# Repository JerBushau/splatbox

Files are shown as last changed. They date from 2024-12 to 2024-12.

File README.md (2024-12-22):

# Splatbox Fightstick

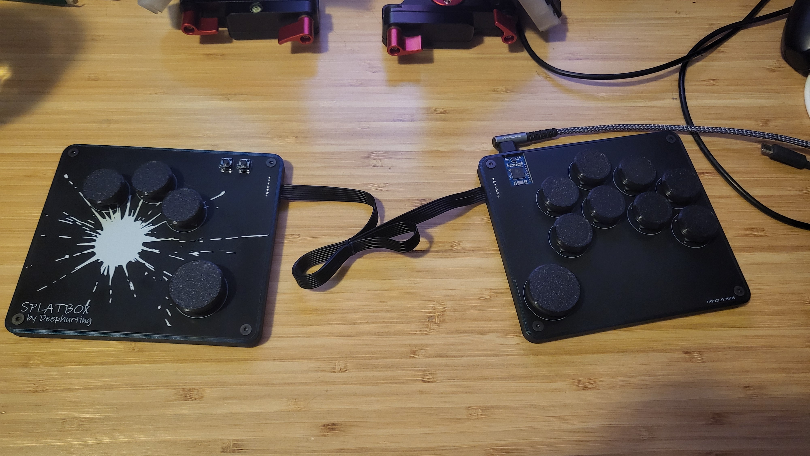
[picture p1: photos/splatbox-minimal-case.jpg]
Splatbox


A prototype for a split ergonomic fightstick inspired by [Flatbox](https://github.com/jfedor2/flatbox). Designed to provide a more ergonomic and comfortable DIY option for anyone that might be interested in such a thing. This project also serves as an opportunity for me to do some handwiring and learn Autodesk Fusion and KiCad.

## BOM

- PCB
- Waveshare rp2040 zero
- 13 x choc switches (pictured are [LowProKBs Twilight switches](https://lowprokb.ca/collections/switches/products/ambients-silent-choc-switches?variant=44873426436260))
- 2 x tact switches (Start and Select buttons)
- 8 x M3 6mm screws
- 8 x M3 heat-set inserts
- 28 awg ribbon cable (at least 7 pin)
- 3D printed case (minimal)
- 11 x Small 3D printed [button caps](https://github.com/jfedor2/flatbox/tree/master/3d-printed-buttoncaps)
- 2 x Big 3D printed [button caps](https://github.com/jfedor2/flatbox/tree/master/3d-printed-buttoncaps)
- Rubber feet

## Building

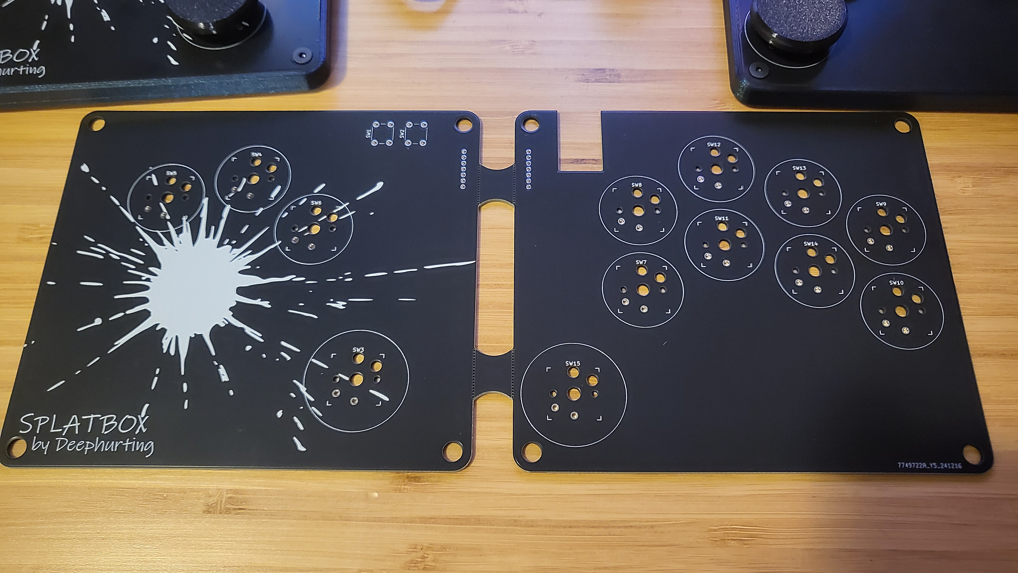
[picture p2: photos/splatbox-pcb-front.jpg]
Splatbox Splatbox pcb


While still far from a finished product, the pcb certainly adds to the stability and reliability of the build. The tolerances for the case files are extremely tight, so you will likely need to scale it up some small fraction, I had to sand the pcb a bit to get a good fit.

- Set heat-set inserts in case
- Solder rp2040 zero
- Solder switches
- Solder ribbon cable to one side or the other
- Feed cable through the holes and solder the remaining side
- Screw the pcb to the case

## TODO:

- [x] PCB design: Create a custom PCB to improve durability and simplify the design
- [x] Case re-design to accommodate the PCB layout
  - [ ] More case options
- [ ] More modularity: Implement a way to extend or shorten the cable
- [ ] Wireless version (dongle approach): Explore a wireless setup using XIAO Seeeds

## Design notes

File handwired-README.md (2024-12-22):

# Splatbox Fightstick

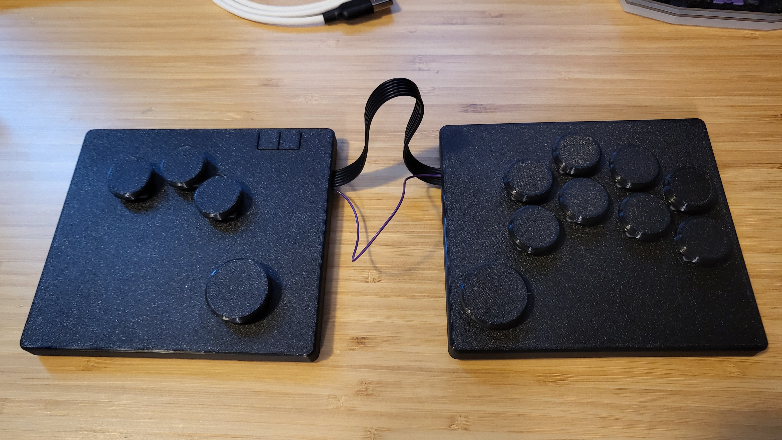
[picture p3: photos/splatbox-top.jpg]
Splatbox

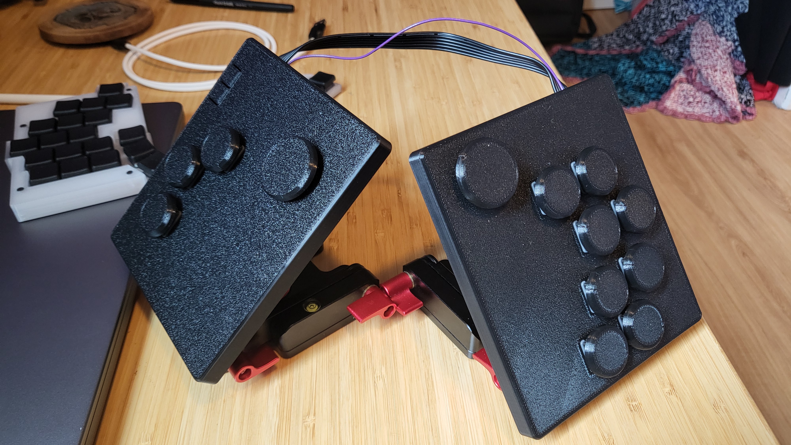
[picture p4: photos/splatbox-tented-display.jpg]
Splatbox Splatbox with tenting


An early prototype for a split ergonomic fightstick inspired by [Flatbox](https://github.com/jfedor2/flatbox). Designed to provide a more ergonomic and comfortable DIY option for anyone that might be interested in such a thing. This project also serves as an opportunity for me to learn Autodesk Fusion and KiCad.

## BOM (as shown)

- Waveshare rp2040 zero
- 13 x choc switches (pictured are [LowProKBs Twilight switches](https://lowprokb.ca/collections/switches/products/ambients-silent-choc-switches?variant=44873426436260))
- 2 x tact switches (Start and Select buttons)
- 8 x M3 6mm screws
- 8 x M3 heat-set inserts
- Wire
- 3D printed case
- 11 x Small 3D printed [button caps](https://github.com/jfedor2/flatbox/tree/master/3d-printed-buttoncaps)
- 2 x Big 3D printed [button caps](https://github.com/jfedor2/flatbox/tree/master/3d-printed-buttoncaps)
- Rubber feet

## Building

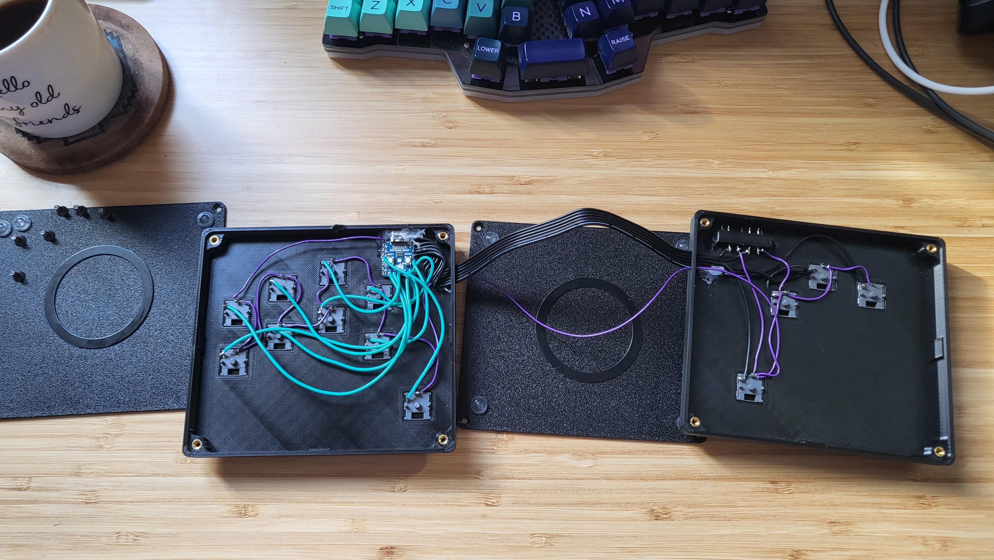
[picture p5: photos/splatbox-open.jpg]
Splatbox Splatbox open


This is very much a Proof of Concept, and the build was quick and dirty. But, if you want to make one here's a rundown of the steps:

- Flash the RP2040 ([GP2040-CE firmware](https://gp2040-ce.info/downloads/))
- 3D print the case (I used PETG, but it has a bit too much flex; consider using a more rigid filament)
- Set the M3 heat-set inserts
- Glue the tact switches to the tact switch holder (3D-printed)
- Glue the tact switch holder to the case
- Insert choc switches into the case
- Wire everything up to the RP2040 ([wiring guide](https://gp2040-ce.info/controller-build/wiring/#waveshare-rp2040-zero))
- Glue as needed
- Assemble the case by screwing on the bottom with 8 x M3 screws

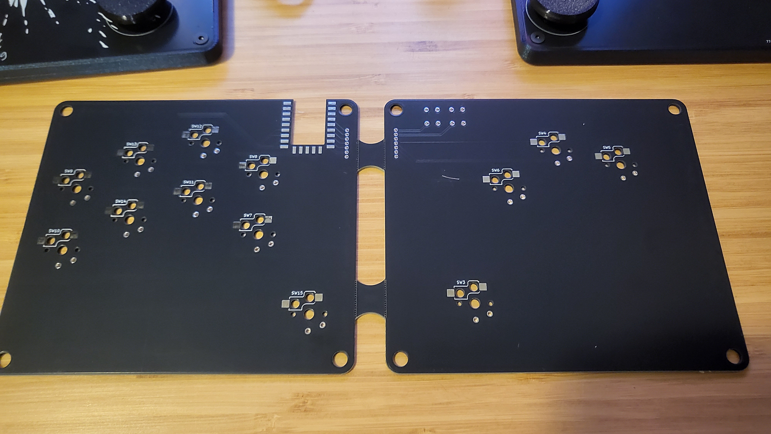
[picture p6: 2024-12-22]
photos/splatbox-pcb-back.jpg

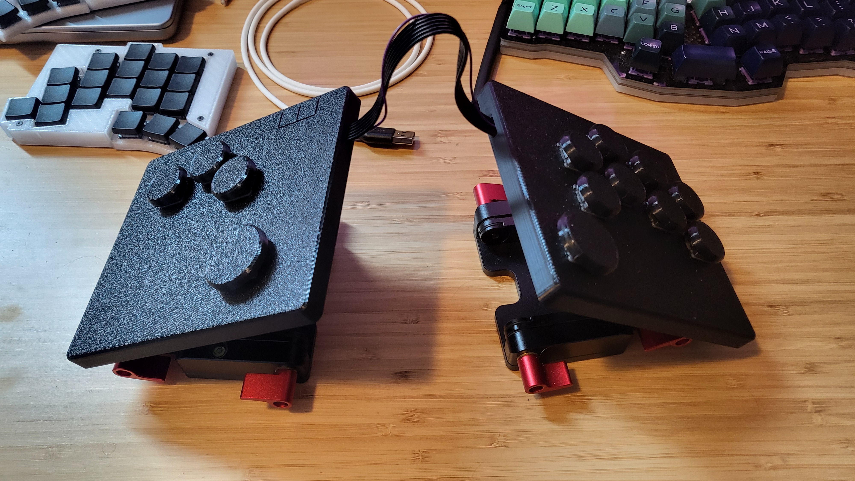
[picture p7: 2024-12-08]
photos/splatbox-tented-practical.jpg

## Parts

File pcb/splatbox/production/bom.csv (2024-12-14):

Designator | Footprint | Quantity | Value | LCSC Part #
RIBBON_CONNECTOR1, RIBBON_CONNECTOR3 | ribbon connector | 2 | ~
SW1, SW2 | SW_PUSH_6mm | 2 | Switch
SW10, SW11, SW12, SW13, SW14, SW15, SW3, SW4, SW5, SW6, SW7, SW8, SW9 | Kailh_socket_PG1350_optional | 13 | Switch
U1 | RP2040-Zero | 1 | RP2040-Zero

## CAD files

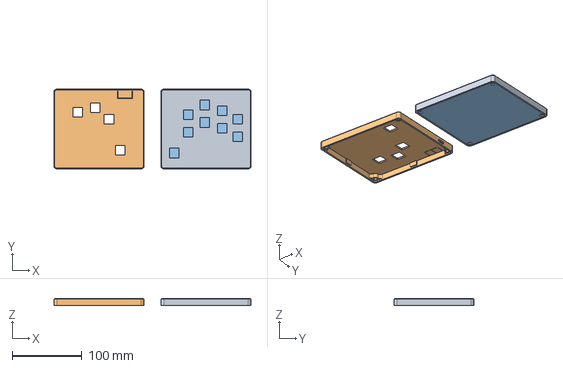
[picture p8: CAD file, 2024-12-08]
cad/handwire/splatbox_v0.0.1.step
283.2 x 114.7 x 10.0 mm

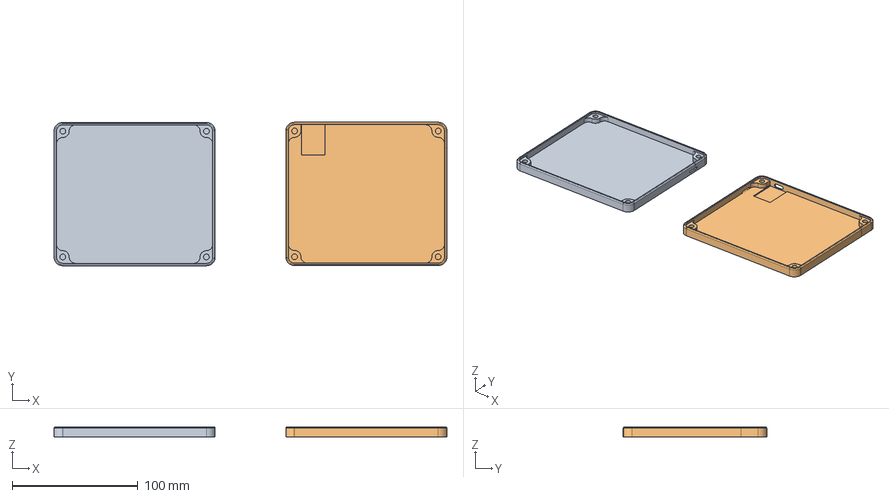
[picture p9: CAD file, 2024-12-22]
cad/minimal/splatbox-minimal.step
312.0 x 114.0 x 8.00 mm

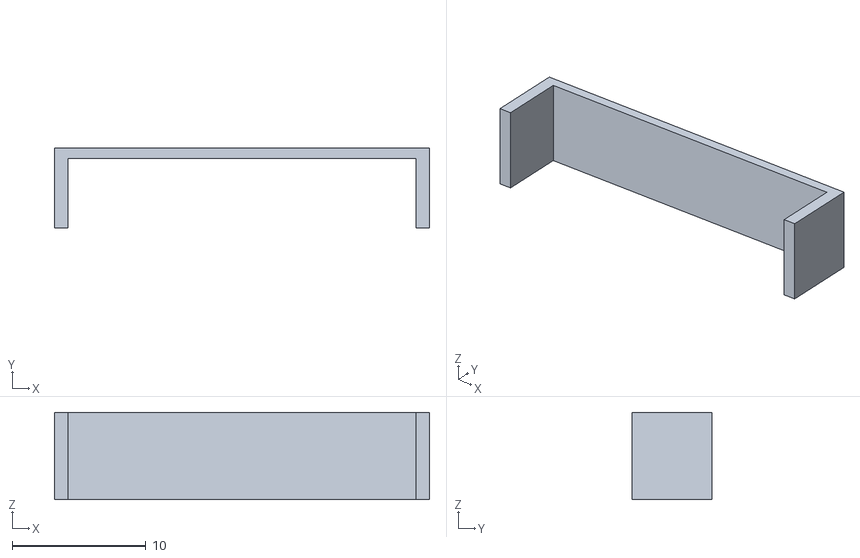
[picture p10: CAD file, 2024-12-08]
case/handwire/splatbox-tact-switch-holder.stl
28.0 x 6.00 x 6.50

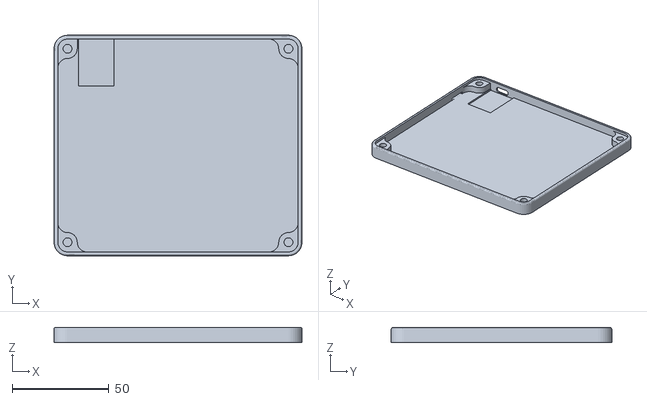
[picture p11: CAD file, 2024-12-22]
case/v0.1.0/minimal-pcb-case/splatbox-minimal-right.stl
128.0 x 113.9 x 8.00

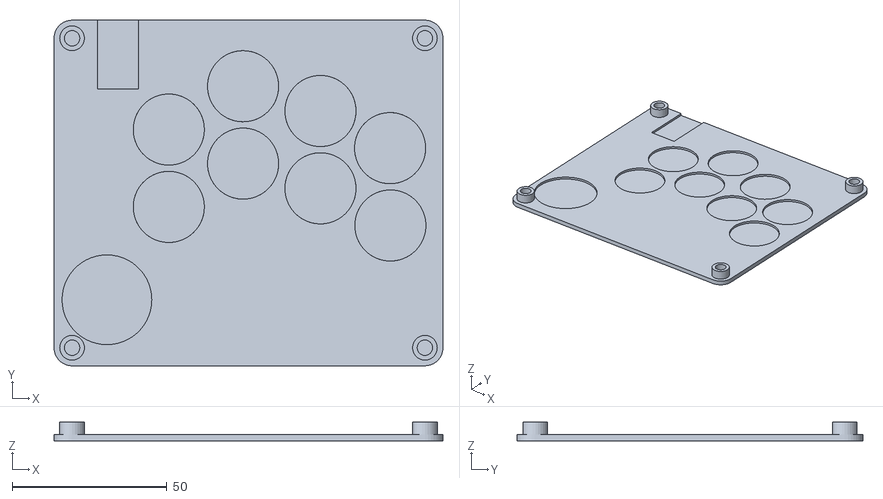
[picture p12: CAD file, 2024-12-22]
case/v0.1.0/ugly-case/caseRightBottom.stl
125.7 x 111.7 x 6.05

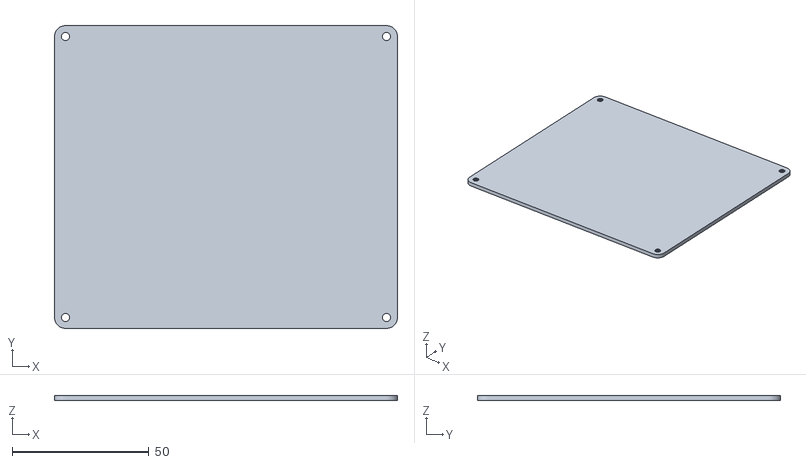
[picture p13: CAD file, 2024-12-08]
case/handwire/splatbox-bottom_v0.0.1.stl
125.4 x 110.7 x 2.00

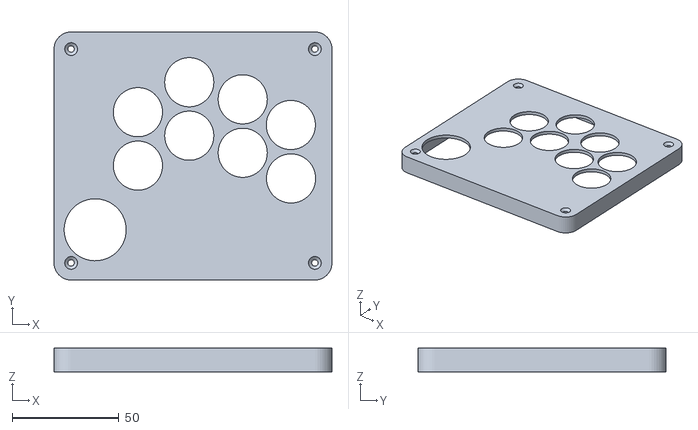
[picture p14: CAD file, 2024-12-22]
case/v0.1.0/ugly-case/caseRightTop.stl
130.0 x 116.0 x 11.0

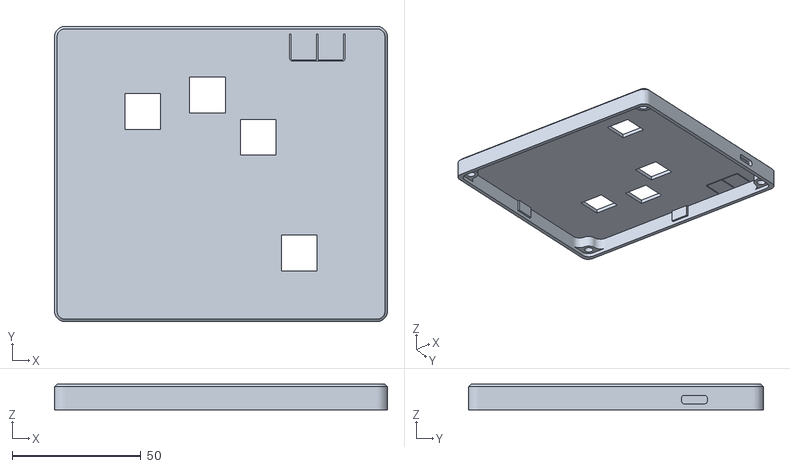
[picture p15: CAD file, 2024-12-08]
case/handwire/splatbox-left_v0.0.4.stl
129.4 x 114.7 x 10.0

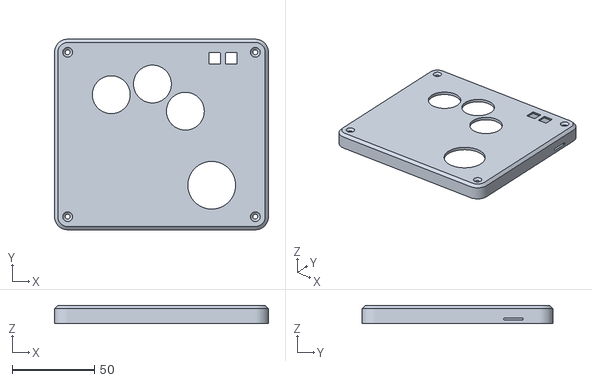
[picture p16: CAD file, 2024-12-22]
case/v0.1.0/ugly-case/caseLeftTop.stl
130.0 x 115.8 x 11.0

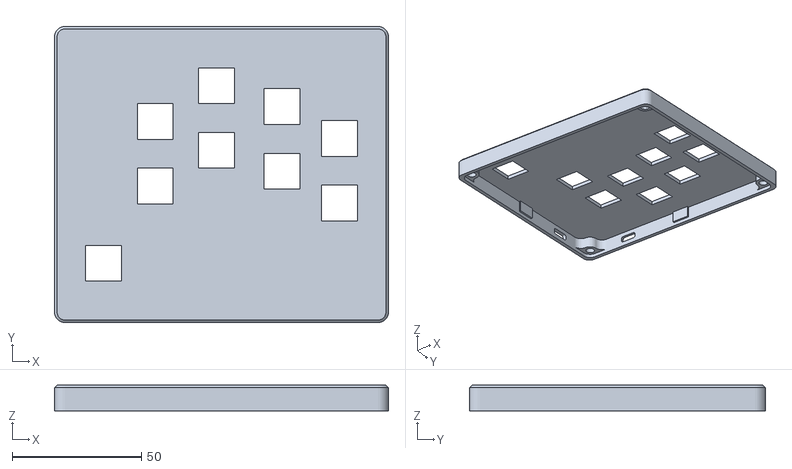
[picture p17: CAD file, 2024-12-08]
case/handwire/splatbox-right_v0.0.3.stl
129.4 x 114.7 x 10.0

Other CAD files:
case/v0.1.0/minimal-pcb-case/splatbox-minimal-left.stl
case/v0.1.0/ugly-case/caseLeftBottom.stl

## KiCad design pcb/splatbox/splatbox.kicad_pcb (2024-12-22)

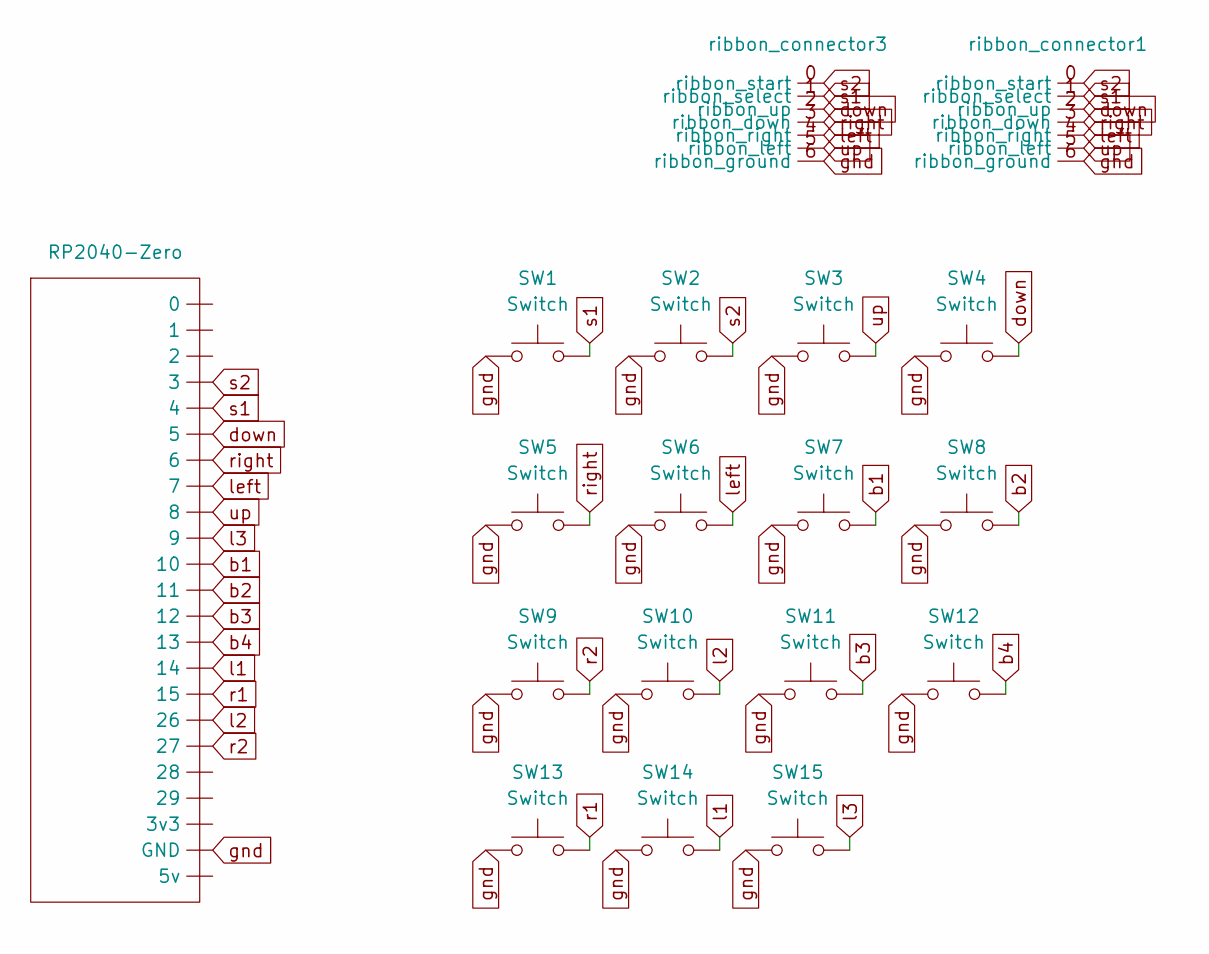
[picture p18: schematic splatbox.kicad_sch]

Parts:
SW1, SW2: Switch; SW_PUSH_6mm
SW3, SW4, SW5, SW6, SW7, SW8, SW9, SW10, SW11, SW12, SW13, SW14, SW15: Switch; Kailh_socket_PG1350_optional
U1: RP2040-Zero
ribbon_connector1, ribbon_connector3: ribbon connector

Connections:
b1: SW7.2, U1.10
b2: SW8.2, U1.11
b3: SW11.2, U1.12
b4: SW12.2, U1.13
down: SW4.2, U1.5, ribbon_connector1.2 (ribbon_up), ribbon_connector3.2 (ribbon_up)
gnd: SW1.1, SW2.1, SW3.1, SW4.1, SW5.1, SW6.1, SW7.1, SW8.1, SW9.1, SW10.1, SW11.1, SW12.1, SW13.1, SW14.1, SW15.1, U1.GND, ribbon_connector1.6 (ribbon_ground), ribbon_connector3.6 (ribbon_ground)
l1: SW14.2, U1.14
l2: SW10.2, U1.26
l3: SW15.2, U1.9
left: SW6.2, U1.7, ribbon_connector1.4 (ribbon_right), ribbon_connector3.4 (ribbon_right)
r1: SW13.2, U1.15
r2: SW9.2, U1.27
right: SW5.2, U1.6, ribbon_connector1.3 (ribbon_down), ribbon_connector3.3 (ribbon_down)
s1: SW1.2, U1.4, ribbon_connector1.1 (ribbon_select), ribbon_connector3.1 (ribbon_select)
s2: SW2.2, U1.3, ribbon_connector1.0 (ribbon_start), ribbon_connector3.0 (ribbon_start)
up: SW3.2, U1.8, ribbon_connector1.5 (ribbon_left), ribbon_connector3.5 (ribbon_left)

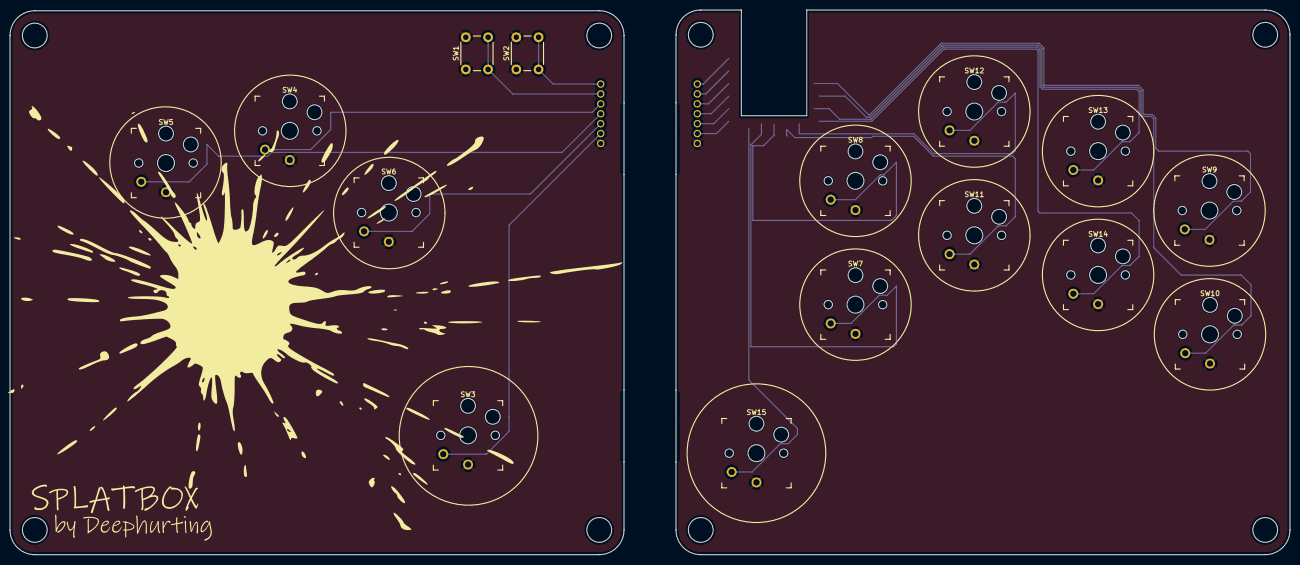
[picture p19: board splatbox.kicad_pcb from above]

Board: 2 copper layers, 258.5 x 110.0 mm, 18 parts (0 on the bottom side), 16 nets.

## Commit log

2024-12-08 Update bom to include printing button caps
2024-12-14 First pass pcb - not working with JLC
    [bom.csv, designators.csv, positions.csv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]
2024-12-15 Add mousebites to connect panels; Add silk screen
    [designators.csv, splatbox.kicad_pcb]
2024-12-15 Remove all except gerber
    [bom.csv, designators.csv, positions.csv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]
2024-12-22 Add pcb files; Add minimal case design; Add photos; Update readme
    [bom.csv, caseLeftBottom.stl, caseLeftTop.stl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]
2024-12-22 Add step file for minimal case
    [splatbox-minimal.step]
2024-12-22 Reorganize folders a bit
    [caseLeftBottom.stl, caseLeftTop.stl, splatbox-minimal-left.stl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]
2024-12-22 Add ugly case right side
    [caseRightBottom.stl, caseRightTop.stl]
